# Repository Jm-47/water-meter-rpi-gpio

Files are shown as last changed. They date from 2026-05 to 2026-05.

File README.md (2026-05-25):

# Water Meter Pulse Counter — Direct Raspberry Pi GPIO (No ESP, No Wi-Fi)

A simple, reliable water consumption monitor using an inductive proximity sensor wired directly to a Raspberry Pi. No ESP32, no Wi-Fi, no cloud.



## Why?

Most DIY water meter projects use an ESP8266/ESP32 with ESPHome to read pulses from the meter and send them to Home Assistant over Wi-Fi. This works, but adds complexity and a wireless failure point.

If your Raspberry Pi (running Home Assistant) is close enough to run a cable to the water meter, you can skip the ESP entirely and read the sensor pulses straight from the Pi's GPIO pins.

**Inspired by** [Pieter Brinkman's water sensor guide](https://www.pieterbrinkman.com/2022/02/02/build-a-cheap-water-usage-sensor-using-esphome-home-assistant-and-a-proximity-sensor/) — simplified by removing the ESP and Wi-Fi layer.

## Architecture

```
┌──────────────┐ ┌──────────────────┐                         ┌──────────────────┐
│  Water Meter │ │ Proximity sensor │  ◄── RJ45 cable ────►   │   Raspberry Pi   │
│              │ └──────────────────┘   (5V, GND, Signal)     │ (Home Assistant) │
└──────────────┘ [3D-printed support]                         └──────────────────┘
```

## Photos

<!-- TODO: Add your own photos here -->

Overview of the complete setup
*The full setup: sensor on the meter, cable run, voltage divider at the Pi.*

Proximity sensor mounted on water meter
*LJ18A3-8Z/BX proximity sensor zip-tied to the water meter.*

Wiring at the sensor end
*Sensor wires connected to the cable.*

Voltage divider at the Raspberry Pi end
*Simple 10kΩ + 20kΩ voltage divider before the GPIO pin.*

Home Assistant Energy Dashboard showing water consumption
*Water consumption visible in the Home Assistant Energy Dashboard.*

## Bill of Materials

| Item | Approx. Cost | Notes |
|---|---|---|
| LJ18A3-8Z/BX proximity sensor (5V) | ~€4 | Must be the 5V version with built-in resistor |
| RJ45 cable (Cat5e/Cat6) | ~€2-5 | Up to 10m, using twisted pairs for each function |
| 10kΩ + 20kΩ resistors | ~€0.10 | For 5V→3.3V voltage divider |
| **Total** | **~€5-10** | |

## Wiring

### Wire Assignment

Only 3 wires are needed (use twisted pairs in the RJ45 cable — pair each signal wire with its return for noise rejection):

| Wire | Function | Sensor Wire Color | RJ45 Pair | Pi Connection |
|---|---|---|---|---|
| 1 | +5V Power | Brown/Orange (VIN) | Pair 1 (e.g. orange + orange/white) | Pi 5V (physical pin 2 or 4) |
| 2 | Signal | Black | Pair 2 (e.g. green + green/white) | Pi GPIO17 (physical pin 11) via voltage divider |
| 3 | Ground | Blue | Shared return on both pairs | Pi GND (physical pin 6 or 9) |

### Voltage Divider (Required!)

The Pi GPIO pins are **3.3V only**. The LJ18A3 outputs 5V. You need a simple resistor divider at the Pi end:

```
Sensor Signal (5V) ──┐
                   [10kΩ]
                     ├─── GPIO17 (3.3V safe)
                   [20kΩ]
                     │
                    GND
```

This gives: 5V × 20kΩ / (10kΩ + 20kΩ) = 3.33V ✓

Using 10kΩ + 20kΩ (instead of 1kΩ + 2kΩ) reduces current draw to ~0.17mA while remaining low enough impedance to avoid noise issues on cable runs up to 10m.

### Wiring Diagram

```
AT THE WATER METER                                      AT THE RASPBERRY PI
==================                                      ===================

  LJ18A3-8Z/BX                                           Raspberry Pi GPIO
  ┌───────────┐         RJ45 cable (< 10m)               ┌──────────────┐
  │ VIN (5V) ─┼──── Pair 1 ──────────────────────────────┼─ 5V (pin 2)  │
  │           │                                          │              │
  │   Signal ─┼──── Pair 2 ─────────────(5V)───┐         │              │
  │           │                             [10kΩ]       │              │
  │           │                                ├──(3.3V)─┼─ GPIO17      │
  │           │                             [20kΩ]       │  (pin 11)    │
  │           │                                │         │              │
  │      GND ─┼──── Shared return ─────────────┴─────────┼─ GND (pin 6) │
  └───────────┘                                          └──────────────┘
```

## Software Setup

The included Python script reads GPIO pulses and publishes water consumption to Home Assistant via MQTT. It handles debouncing and fast flow rates reliably.

See [`water_meter.py`](water_meter.py) for the full implementation.

### Deploying to the Raspberry Pi

You need to copy the script and service file to your Pi. The method depends on your setup:

**Option A: SSH/SCP (works with any Linux-based setup)**

If you have SSH access (Raspberry Pi OS, HA Supervised, or HAOS with the SSH app):

```bash
scp water_meter.py water-meter.service <user>@<pi-ip>:~/
```

Then SSH in:

```bash
ssh <user>@<pi-ip>
```

**Option B: File Editor app (HAOS)**

Open the File Editor app in Home Assistant's sidebar, navigate to the desired location, and paste the file contents directly in the browser.

**Option C: Samba share (HAOS)**

Install the "Samba share" app from the Home Assistant app store, then copy the files over your local network to the exposed share.

**Option D: USB drive**

Copy the files to a USB stick, plug it into the Pi, and mount it to retrieve them.

### HAOS-Specific Setup

> **Important**: On HAOS (Home Assistant OS), you must use the **"Advanced SSH & Web Terminal"** app (community), not the basic "Terminal & SSH" app. The basic app does not expose GPIO devices to the container.
>
> After installing "Advanced SSH & Web Terminal":
> 1. Configure SSH credentials (password or authorized key)
> 2. Start the app
> 3. Verify GPIO access: `ls /dev/gpiochip*`
> 4. If GPIO devices are not visible, try toggling **"Protection mode" OFF** on the app's Info page and restart

#### Install dependencies

```bash
apk add py3-pip
pip3 install --break-system-packages gpiod paho-mqtt
```

#### MQTT configuration

In HAOS, the Mosquitto broker runs in a separate container (app) and requires authentication. Set the environment variables:

```bash
MQTT_HOST=core-mosquitto MQTT_USER=your_user MQTT_PASSWORD=your_pass python3 ~/homeassistant/water_meter.py
```

Use the same MQTT credentials that your Home Assistant MQTT integration uses (check Settings → Devices & Services → MQTT).

#### Run as a background process

The SSH app container is ephemeral — pip packages and files outside of `~/homeassistant/` are lost on restart. Use the app's **init_commands** setting to auto-install and launch on every start.

In the Advanced SSH & Web Terminal app's **Configuration** tab, add this init command:

```
apk add --quiet py3-pip && pip3 install --break-system-packages --quiet gpiod paho-mqtt && MQTT_HOST=core-mosquitto MQTT_USER=your_user MQTT_PASSWORD=your_pass nohup python3 /root/homeassistant/water_meter.py > /var/log/water-meter.log 2>&1 &
```

Replace `your_user` and `your_pass` with your MQTT credentials. Save and restart the app.

Also enable **"Start on boot"** on the app's Info page so the script launches automatically after a Pi reboot.

This handles dependency installation and script launch automatically every time the app starts.

### Raspberry Pi OS Setup

#### Install dependencies

```bash
pip install gpiod paho-mqtt
```

#### Run as a systemd service

```bash
sudo cp water_meter.py /opt/water_meter.py
sudo cp water-meter.service /etc/systemd/system/
sudo systemctl enable water-meter
sudo systemctl start water-meter
```

## Home Assistant Configuration

### Sensor (automatic)

The Python script publishes an MQTT auto-discovery message. The entity `sensor.water_meter_total` will appear automatically in Home Assistant — no manual sensor configuration needed.

### Utility Meters (recommended)

Add the following to your `configuration.yaml` to track consumption over time periods:

```yaml
utility_meter:
  water_hourly:
    source: sensor.water_meter_gpio_water_meter_total
    cycle: hourly
  water_daily:
    source: sensor.water_meter_gpio_water_meter_total
    cycle: daily
  water_monthly:
    source: sensor.water_meter_gpio_water_meter_total
    cycle: monthly
  water_yearly:
    source: sensor.water_meter_gpio_water_meter_total
    cycle: yearly
```

Restart Home Assistant after adding this.

### Energy Dashboard

1. Go to **Settings → Dashboards → Energy**
2. In the **Water consumption** section, click **Add water source**
3. Select `sensor.water_meter_gpio_water_meter_total`
4. Save

Water usage will now appear in the Energy Dashboard.

See [`configuration.yaml`](configuration.yaml) for the full reference config and [`lovelace.yaml`](lovelace.yaml) for a custom dashboard card example.

## Sensor Placement

The proximity sensor detects the small metal disc embedded in your water meter's spinning wheel. Each full rotation = 1 pulse = 1 liter (check your meter — this varies).

1. Open a tap and watch the meter's small wheel spin
2. Hold the sensor flat against the meter face, over the spinning wheel
3. The red LED on the sensor lights up each time the magnet passes
4. Secure with zip ties or velcro

## Comparison with ESP-based Approach

| | ESP + Wi-Fi (traditional) | Direct GPIO (this project) |
|---|---|---|
| Controller | ESP8266/ESP32 | None — Pi GPIO |
| Communication | Wi-Fi | Wired (direct cable) |
| Software | ESPHome | HA integration or Python |
| Reliability | Depends on Wi-Fi | Rock solid |
| Components | Sensor + ESP + USB power | Sensor + 2 resistors |
| Cost | ~€10 | ~€5-10 |
| Latency | ~1-6s (Wi-Fi polling) | Instant (hardware interrupt) |

## Troubleshooting

- **No pulses detected**: Check voltage divider output with a multimeter (should read ~3.3V when sensor triggers). Verify sensor LED blinks when water flows.
- **Double counting**: Increase debounce time in the Python script or add a hardware capacitor (100nF) across the GPIO pin.
- **Signal noise over long cable**: The RJ45 twisted pairs help reject interference. If you still get noise, try adding a 100nF capacitor across GPIO17 to GND, or switch to lower value resistors (1kΩ + 2kΩ).
- **Sensor doesn't detect magnet**: Try repositioning — the sensing distance is ~8mm. Some meters have weaker magnets.

## License

MIT — do whatever you want with this.

## Credits

- Original ESP-based approach: [Pieter Brinkman](https://www.pieterbrinkman.com/2022/02/02/build-a-cheap-water-usage-sensor-using-esphome-home-assistant-and-a-proximity-sensor/)
- Simplified wired design: this project

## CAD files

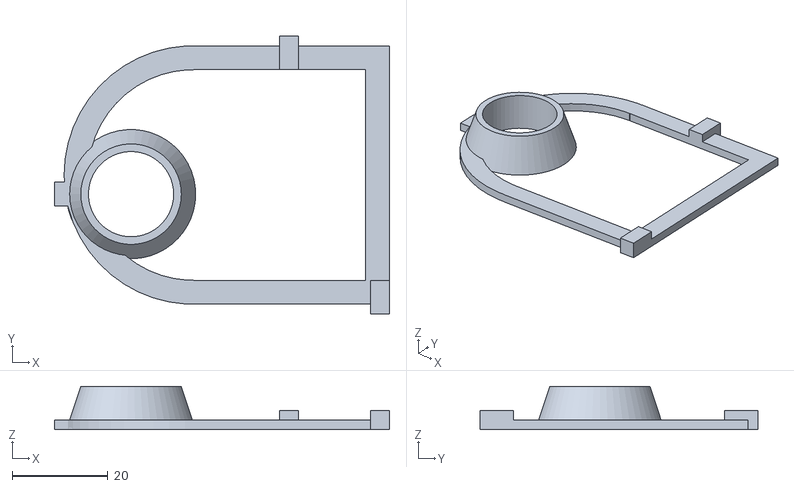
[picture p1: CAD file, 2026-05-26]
3d/WaterMeter.stl
70.0 x 58.0 x 9.00

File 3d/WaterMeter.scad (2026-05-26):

// Itron Aquadis+ DN15 sensor mount for LJ18A3-8Z/BX (M18, Ø18mm)
// Sensor sensing distance: 8mm
// Meter: Itron Aquadis+ R500 16bar T50 (2023)

$fn = 50; // smoother curves for printing

plate_w = 68;
plate_h = 54;
plate_t = 2;

l = 5;

// Sensor holder - tapered cylinder
holder_h = 9;
holder_r1 = 13.5; // base radius
holder_r2 = 10.5; // top radius

// Sensor hole: sized for the actual M18 sensor body
sensor_hole_r = 8.9;

difference() {
  union() {
    difference() {
      union() {
        // Base plate
        translate([plate_h/2, 0, 0])       cube([plate_w-plate_h/2, plate_h, plate_t]);
        translate([plate_h/2, plate_h/2]) cylinder(h = plate_t, r = plate_h/2);

        // Retention tabs ("ergots") - slightly taller for better grip on meter rim
        translate([-2, 20.5, 0])        cube([3, 5, 2]);   // bottom tab
        translate([plate_w - 4, -2, 0]) cube([4, 7, 4]);   // top-right tab
        translate([45, 49, 0])          cube([4, 7, 4]);   // left tab
      }
      union() {
        translate([plate_h/2, l, -1])         cube([plate_w - l - plate_h/2, plate_h - 2*l, plate_t + 2]);  
        translate([plate_h/2, plate_h/2, -1]) cylinder(h = plate_t+2, r = (plate_h)/2-l);
      }
    }

    // Sensor holder
    translate([14, 23, 0])  cylinder(h = holder_h, r1 = holder_r1, r2 = holder_r2);
  }

  // Sensor through-hole
  translate([14, 23, -1]) cylinder(h = holder_h + 2, r = sensor_hole_r);
}

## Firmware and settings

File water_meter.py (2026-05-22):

#!/usr/bin/env python3
"""
Water meter pulse counter for Raspberry Pi GPIO.

Reads pulses from an LJ18A3-8Z/BX proximity sensor connected to a GPIO pin
and publishes the count to Home Assistant via MQTT (with auto-discovery).

Usage:
    python3 water_meter.py

Environment variables (optional):
    MQTT_HOST       - MQTT broker host (default: localhost)
    MQTT_PORT       - MQTT broker port (default: 1883)
    MQTT_USER       - MQTT username (default: none)
    MQTT_PASSWORD   - MQTT password (default: none)
    GPIO_PIN        - GPIO pin number (default: 17)
    DEBOUNCE_MS     - Debounce time in milliseconds (default: 50)
    STATE_FILE      - Path to persist total count across restarts
"""

import json
import os
import signal
import sys
import time

import gpiod
import paho.mqtt.client as mqtt

# Configuration from environment
MQTT_HOST = os.environ.get("MQTT_HOST", "localhost")
MQTT_PORT = int(os.environ.get("MQTT_PORT", "1883"))
MQTT_USER = os.environ.get("MQTT_USER", "")
MQTT_PASSWORD = os.environ.get("MQTT_PASSWORD", "")
GPIO_CHIP = os.environ.get("GPIO_CHIP", "/dev/gpiochip0")
GPIO_PIN = int(os.environ.get("GPIO_PIN", "17"))
DEBOUNCE_MS = int(os.environ.get("DEBOUNCE_MS", "50"))
STATE_FILE = os.environ.get("STATE_FILE", "/var/lib/water-meter/total_liters")

# MQTT topics
DISCOVERY_TOPIC = "homeassistant/sensor/water_meter_total/config"
STATE_TOPIC = "homeassistant/sensor/water_meter_total/state"
ATTR_TOPIC = "homeassistant/sensor/water_meter_total/attributes"


def load_state() -> int:
    """Load persisted total liter count from disk."""
    try:
        with open(STATE_FILE, "r") as f:
            return int(f.read().strip())
    except (FileNotFoundError, ValueError):
        return 0


def save_state(total: int) -> None:
    """Persist total liter count to disk."""
    os.makedirs(os.path.dirname(STATE_FILE), exist_ok=True)
    with open(STATE_FILE, "w") as f:
        f.write(str(total))


def publish_discovery(client: mqtt.Client) -> None:
    """Publish MQTT auto-discovery config for Home Assistant."""
    config = {
        "name": "Water Meter Total",
        "unique_id": "water_meter_rpi_gpio_total",
        "state_topic": STATE_TOPIC,
        "json_attributes_topic": ATTR_TOPIC,
        "unit_of_measurement": "L",
        "device_class": "water",
        "state_class": "total_increasing",
        "icon": "mdi:water",
        "device": {
            "identifiers": ["water_meter_rpi_gpio"],
            "name": "Water Meter (GPIO)",
            "model": "LJ18A3-8Z/BX + Raspberry Pi",
            "manufacturer": "DIY",
        },
    }
    client.publish(DISCOVERY_TOPIC, json.dumps(config), retain=True)


def main():
    total_liters = load_state()
    print(f"Starting water meter counter. Loaded state: {total_liters} L")

    # MQTT setup
    client = mqtt.Client(mqtt.CallbackAPIVersion.VERSION2)
    if MQTT_USER:
        client.username_pw_set(MQTT_USER, MQTT_PASSWORD)

    connected = False

    def on_connect(client, userdata, flags, reason_code, properties=None):
        nonlocal connected
        if reason_code == 0:
            print("MQTT connected successfully")
            connected = True
        else:
            print(f"MQTT connection failed: {reason_code}")

    client.on_connect = on_connect
    client.connect(MQTT_HOST, MQTT_PORT, keepalive=60)
    client.loop_start()

    # Wait for connection
    for _ in range(50):
        if connected:
            break
        time.sleep(0.1)

    if not connected:
        print("ERROR: Could not connect to MQTT broker")
        sys.exit(1)

    # Publish discovery and initial state
    publish_discovery(client)
    client.publish(STATE_TOPIC, str(total_liters), retain=True)
    print(f"Published discovery and initial state: {total_liters} L")

    # GPIO setup
    chip = gpiod.Chip(GPIO_CHIP)
    line_request = gpiod.request_lines(
        GPIO_CHIP,
        consumer="water_meter",
        config={GPIO_PIN: gpiod.LineSettings(edge_detection=gpiod.line.Edge.RISING)},
    )

    last_event_ms = 0
    pulses_since_save = 0

    # Graceful shutdown
    def shutdown(signum, frame):
        print(f"\nShutting down. Total: {total_liters} L")
        save_state(total_liters)
        client.publish(STATE_TOPIC, str(total_liters), retain=True)
        client.disconnect()
        line_request.release()
        sys.exit(0)

    signal.signal(signal.SIGTERM, shutdown)
    signal.signal(signal.SIGINT, shutdown)

    print(f"Listening for pulses on GPIO{GPIO_PIN} (debounce: {DEBOUNCE_MS}ms)")

    while True:
        if line_request.wait_edge_events(timeout=10):
            events = line_request.read_edge_events()
            for event in events:
                now_ms = event.timestamp_ns // 1_000_000

                # Debounce
                if now_ms - last_event_ms < DEBOUNCE_MS:
                    continue

                last_event_ms = now_ms
                total_liters += 1
                pulses_since_save += 1

                # Publish to MQTT
                client.publish(STATE_TOPIC, str(total_liters), retain=True)
                client.publish(
                    ATTR_TOPIC,
                    json.dumps({"last_pulse": time.strftime("%Y-%m-%dT%H:%M:%S")}),
                )

                # Persist every 10 pulses to reduce SD card writes
                if pulses_since_save >= 10:
                    save_state(total_liters)
                    pulses_since_save = 0

                print(f"Pulse! Total: {total_liters} L")


if __name__ == "__main__":
    main()

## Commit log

2026-05-20 Initial commit: water meter pulse counter via Raspberry Pi GPIO
2026-05-20 Remove Option A as the `Raspberry Pi GPIO integration` has been removed
2026-05-22 Fix the script and the Readme
    [water_meter.py]
2026-05-25 Add parametric OpenSCAD sensor mount for Itron Aquadis+
    [WaterMeter.scad]
2026-05-25 Update wiring: 10kΩ+20kΩ divider, RJ45 cable with twisted pairs
2026-05-26 Add stl
    [WaterMeter.stl]
2026-05-26 Better-looking design
    [WaterMeter.scad, WaterMeter.stl]
2026-05-26 move the top right tab
    [WaterMeter.scad, WaterMeter.stl]
